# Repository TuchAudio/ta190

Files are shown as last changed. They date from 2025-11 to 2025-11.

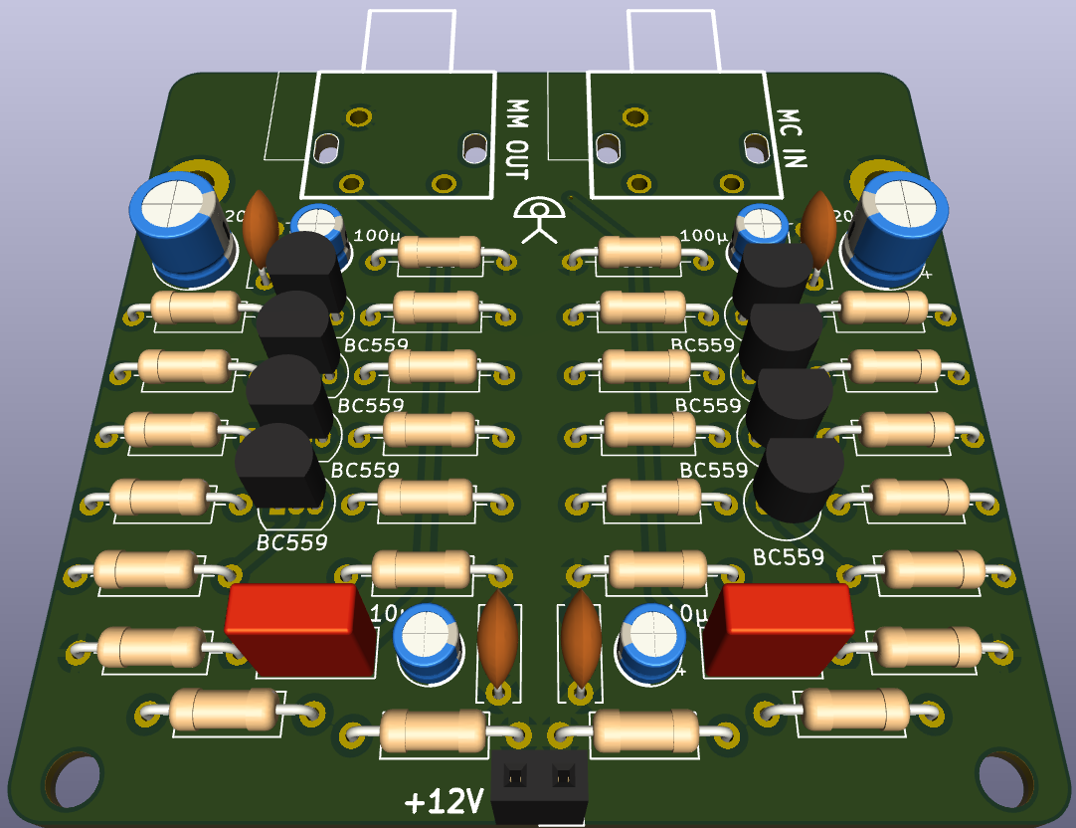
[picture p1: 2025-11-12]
pics/190-render.png

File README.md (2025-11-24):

# ta190
Low Noise Moving-Coil Pre-Amplifier

## Purpose
Generic _standalone_ pre-preamp for **Moving Coil** phono cartridges, applying a fixed linear voltage gain.

## Design
The use of **four _common-base_ stages in parallel**  provides **low input impedance** (100 Ω) and **improved _signal-to-noise_ ratio** (by 6 dB).

## Specs
- **Power supply:** 9-12 V, asymmetrical (just a few mA)
- **Gain:** x33 (+34 dB)
- **Input Sensitivity:** 0.11 mV over 100 Ω (for a 3.6 mV output, suitable for [TuchAudio 103 preamp](../../../ta103))
- **Nominal Output level:** 3.6 mV over 110 kΩ (from a 0.11 mV input)
- **Output impedance:** 3.3 kΩ. _Lower load impedances are allowed, but diminished output level and impaired bass response are to be expected_.

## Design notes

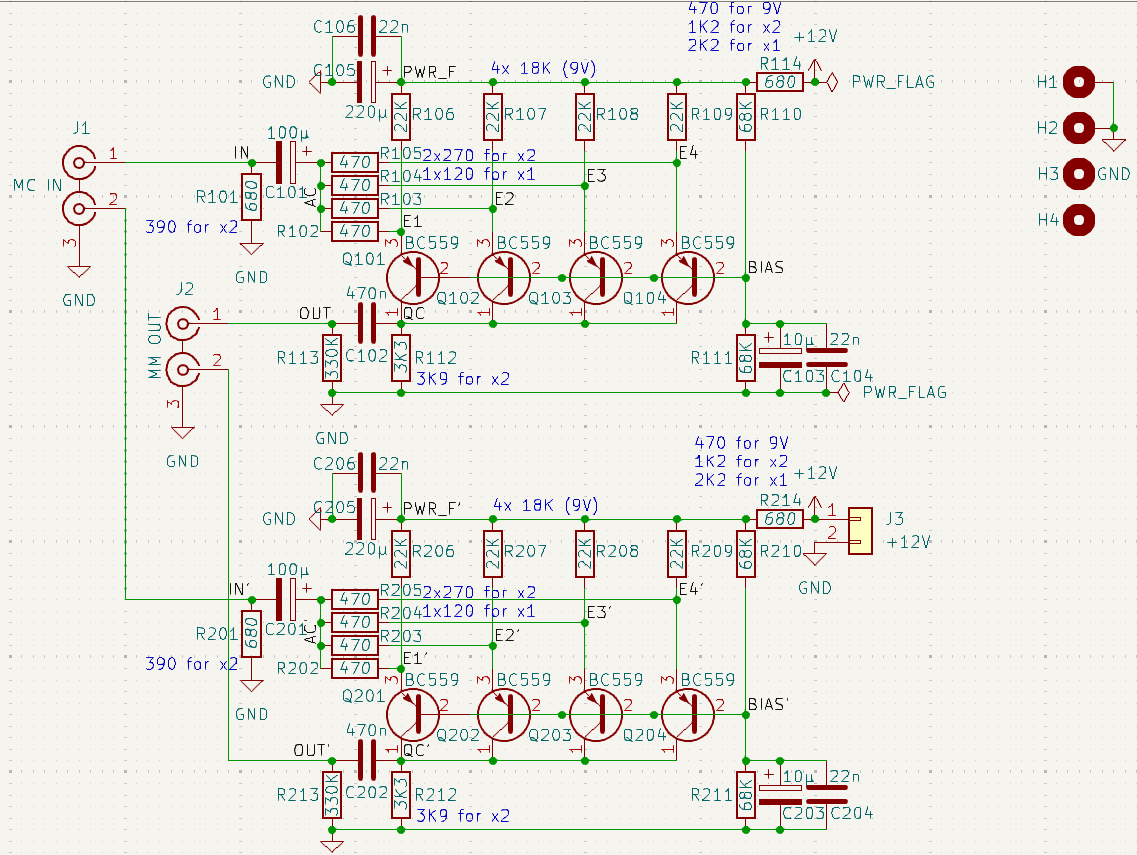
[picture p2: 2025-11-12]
pics/190-schematic.png

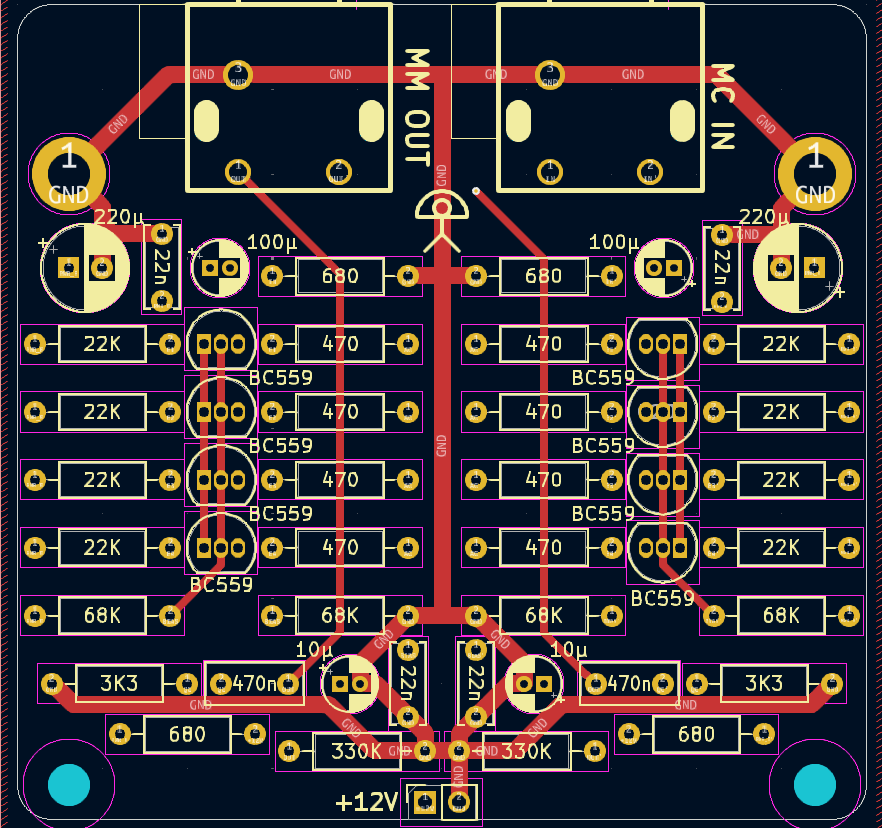
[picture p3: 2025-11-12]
pics/190-pcb-front.png

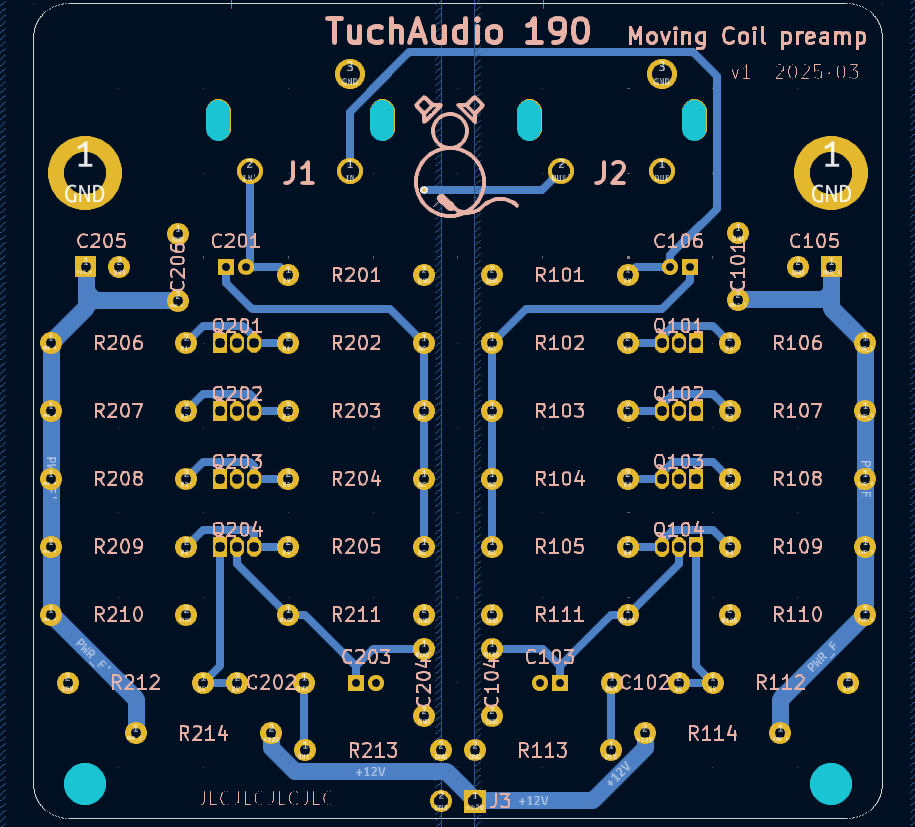
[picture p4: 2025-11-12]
pics/190-pcb-back.png

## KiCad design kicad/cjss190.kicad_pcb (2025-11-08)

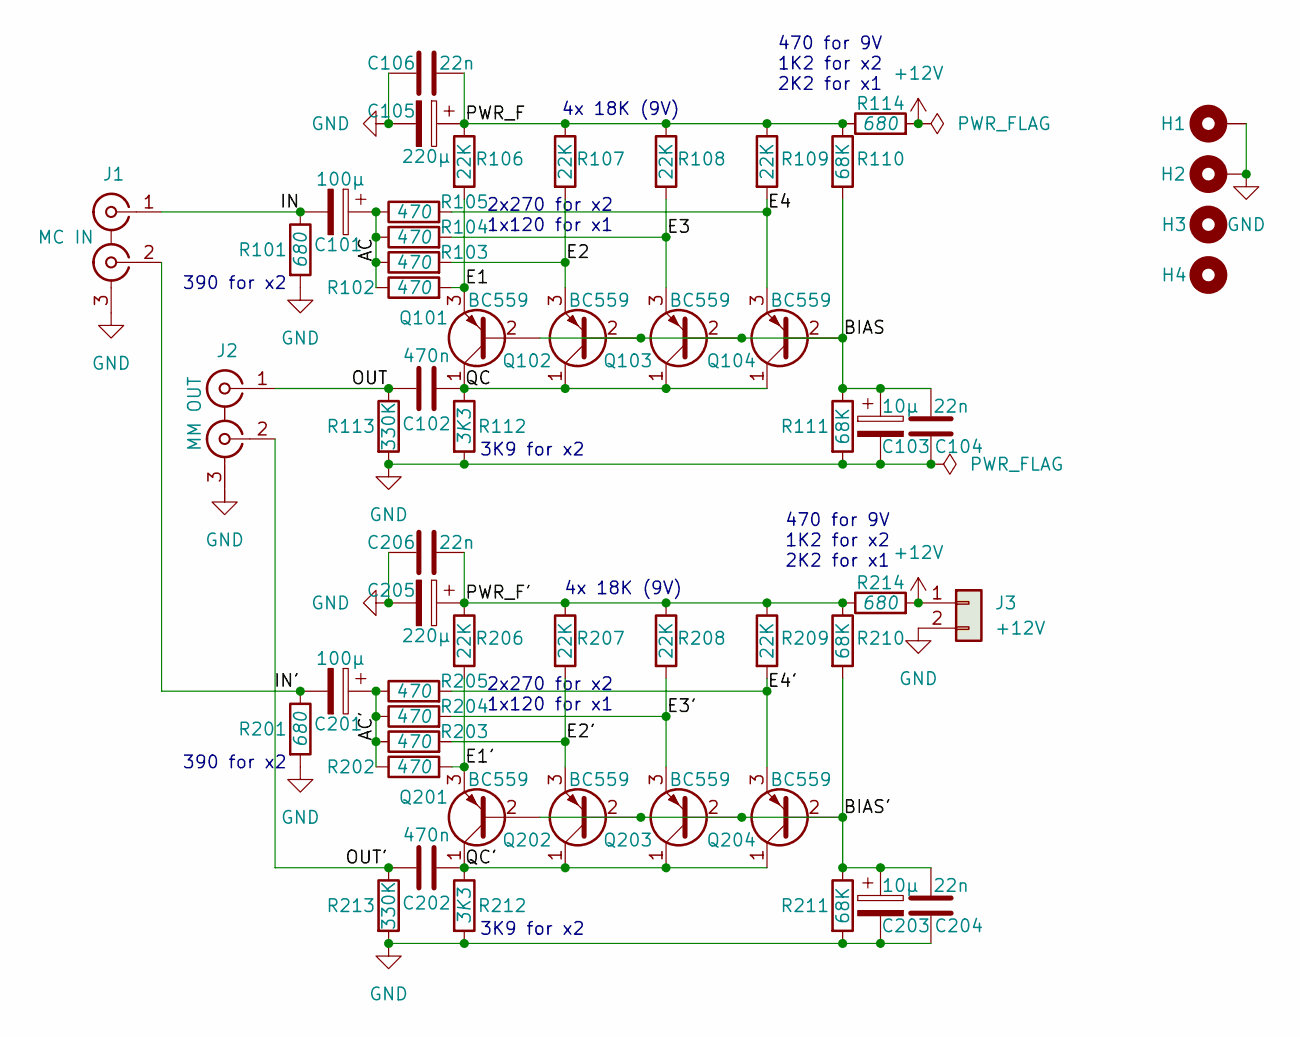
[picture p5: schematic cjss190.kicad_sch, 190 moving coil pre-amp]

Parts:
C101, C201: 100µ; CP_Radial_D4.0mm_P1.50mm
C102, C202: 470n; C_Rect_L7.2mm_W3.0mm_P5.00mm_FKS2_FKP2_MKS2_MKP2
C103, C203: 10µ; CP_Radial_D4.0mm_P1.50mm
C104, C106, C204, C206: 22n; C_Disc_D6.0mm_W2.5mm_P5.00mm
C105, C205: 220µ; CP_Radial_D6.3mm_P2.50mm
H1, H2: MountingHole_Pad; MountingHole_3.2mm_M3_DIN965_Pad
H3, H4: MountingHole; MountingHole_3.2mm_M3
J1: MC IN; 2xRCA_vertical
J2: MM OUT; 2xRCA_vertical
J3: +12V; PinSocket_1x02_P2.54mm_Vertical
Q101, Q102, Q103, Q104, Q201, Q202, Q203, Q204: BC559; TO-92_Inline
R101, R114, R201, R214: 680; R_Axial_DIN0207_L6.3mm_D2.5mm_P10.16mm_Horizontal
R102, R103, R104, R105, R202, R203, R204, R205: 470; R_Axial_DIN0207_L6.3mm_D2.5mm_P10.16mm_Horizontal
R106, R107, R108, R109, R206, R207, R208, R209: 22K; R_Axial_DIN0207_L6.3mm_D2.5mm_P10.16mm_Horizontal
R110, R111, R210, R211: 68K; R_Axial_DIN0207_L6.3mm_D2.5mm_P10.16mm_Horizontal
R112, R212: 3K3; R_Axial_DIN0207_L6.3mm_D2.5mm_P10.16mm_Horizontal
R113, R213: 330K; R_Axial_DIN0207_L6.3mm_D2.5mm_P10.16mm_Horizontal

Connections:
+12V: J3.1, R114.2, R214.2
/AC: C101.1, R102.1, R103.1, R104.1, R105.1
/AC': C201.1, R202.1, R203.1, R204.1, R205.1
/BIAS: C103.1, C104.1, Q101.2 (B), Q102.2 (B), Q103.2 (B), Q104.2 (B), R110.2, R111.1
/BIAS': C203.1, C204.1, Q201.2 (B), Q202.2 (B), Q203.2 (B), Q204.2 (B), R210.2, R211.1
/E1: Q101.3 (E), R102.2, R106.2
/E1': Q201.3 (E), R202.2, R206.2
/E2: Q102.3 (E), R103.2, R107.2
/E2': Q202.3 (E), R203.2, R207.2
/E3: Q103.3 (E), R104.2, R108.2
/E3': Q203.3 (E), R204.2, R208.2
/E4: Q104.3 (E), R105.2, R109.2
/E4': Q204.3 (E), R205.2, R209.2
/IN: C101.2, J1.1 (IN1), R101.1
/IN': C201.2, J1.2 (IN2), R201.1
/OUT: C102.1, J2.1 (IN1), R113.1
/OUT': C202.1, J2.2 (IN2), R213.1
/PWR_F: C105.1, C106.2, R106.1, R107.1, R108.1, R109.1, R110.1, R114.1
/PWR_F': C205.1, C206.2, R206.1, R207.1, R208.1, R209.1, R210.1, R214.1
/QC: C102.2, Q101.1 (C), Q102.1 (C), Q103.1 (C), Q104.1 (C), R112.1
/QC': C202.2, Q201.1 (C), Q202.1 (C), Q203.1 (C), Q204.1 (C), R212.1
GND: C103.2, C104.2, C105.2, C106.1, C203.2, C204.2, C205.2, C206.1, H1.1, H2.1, J1.3 (EXT), J2.3 (EXT), J3.2, R101.2, R111.2, R112.2, R113.2, R201.2, R211.2, R212.2, R213.2

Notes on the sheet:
470 for 9V 1K2 for x2 2K2 for x1
390 for x2
3K9 for x2
4x 18K (9V)
2x270 for x2 1x120 for x1

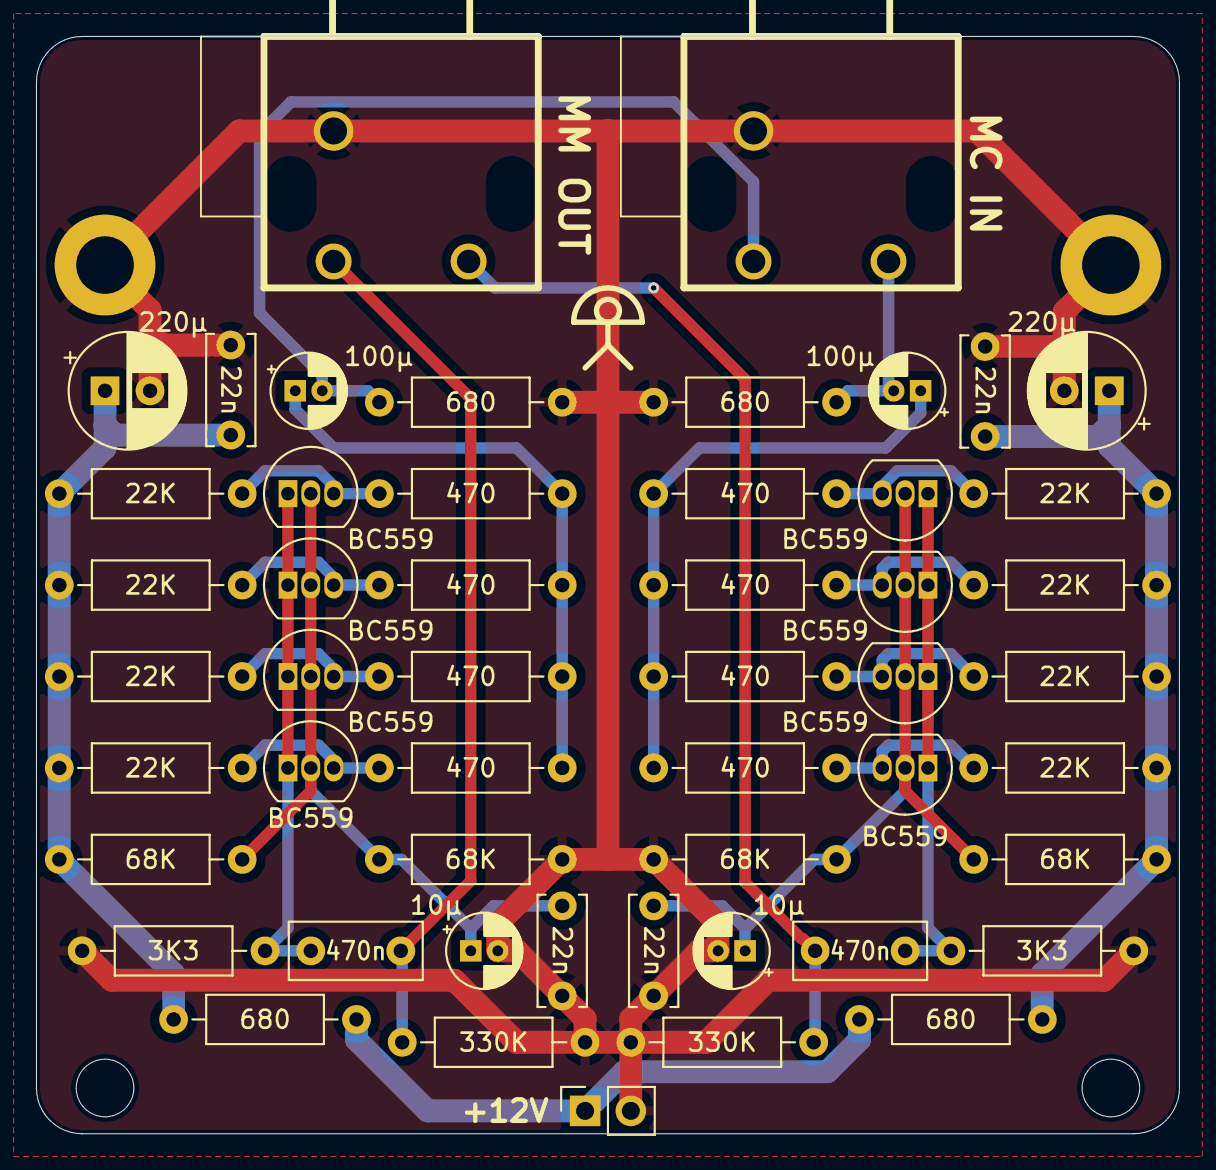
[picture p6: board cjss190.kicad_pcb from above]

Board: 2 copper layers, 63.5 x 61.0 mm, 55 parts (0 on the bottom side), 22 nets.
